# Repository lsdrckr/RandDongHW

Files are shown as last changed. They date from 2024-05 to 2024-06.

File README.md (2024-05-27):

# Stage chez Rang Dong

## Introduction

Dans le cadre de mon stage au Vietnam au Posts and Telecommunications Institute of Technologies, j'ai eu l'occasion de réaliser un projet avec une de leurs entreprise partenaire : Rand Dong. Cette entreprise est spécialisé dans la conception et la vente de matériel pour la domotique (smart home, smart cities...) tels que des lampes connectés, des hubs de capteurs (température, pression...) ou encore des caméras connectés. J'ai eu l'occasion de rejoindre 4 équipes :
- software : design d'application mobiles
- firmware : programmation de systèmes embarqués
- cloud : stockage dans des databases
- hardware : design de circuit imprimé
Mon choix s'est tourné vers le hardware, domaine dans lequel j'ai pu approfondir mes connaissances, et ce principalement d'un point de vue technique, grâce à l'équipe de Rang Dong qui m'a épaulé durant l'entièreté de mon stage.

## Projet

Le projet qui m'a été confié fût de réalisé un "Touch switch". Il s'agit d'interrupteurs tactiles permettant de contrôler, dans le cas de mon projet, 4 lampes. Voici ci-dessous une photo d'un produit commercialisé par Rand Dong sur lequel je vais me baser.

<center>
  <table>
    <tr>
      <td align="center">
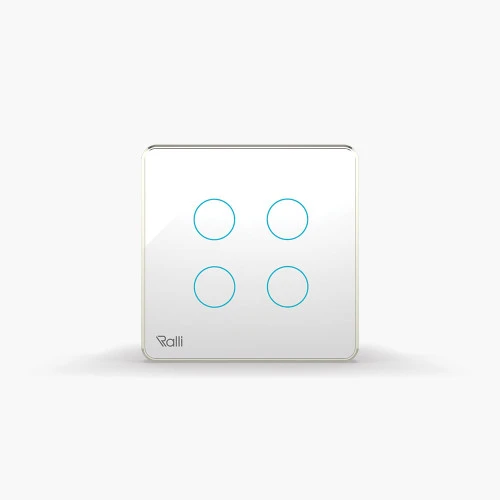
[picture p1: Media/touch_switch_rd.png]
touch_switch_rd
        
        <br>
        <em>Touch Switch de chez Rang Dong</em>
      </td>
    </tr>
  </table>
</center>

A l'aide d'un contact avec le doigt sur l'un des ronds bleus, on allume une lampe à proximité. Ce principe à l'air simple car il est couramment utilisé et il nous accompagne au quotidien. Cependant, nous allons voir comment un tel projet est réalisé du début à la fin. Chez Rang Dong, ce genre d'objets est réalisé en 3 parties :
- une carte servant à l'alimentation (conversion AC/DC, relais...)
- une carte destiné au contrôle (microprocesseur...)
- le design de l'objet en lui-même, dans lequel sont camouflés les précédentes cartes
Dans un premier temps, j'ai conçu la carte servant à l'alimentation.

## Alimentation

### Choix des technologies

Le choix de l'alimentation est très importante pour tout projet, mais il l'est d'autant plus pour un projet comme celui-ci. En effet, ce dernier est destiné à n'importe quel client et de plus, ce client devra être en contact direct avec l'objet s'il souhaite l'utiliser. C'est pourquoi la sécurité était l'argument numéro un lors de mon choix. 2 propositions se sont vite dégagés au sein de l'équipe :
- alimentation buck
- alimentation flyback
D'un côté, l'alimentation buck permet la conversion à l'aide d'une inductance tandis que le flyback utilise un transformateur. De plus, le flyback permet une isolation galvanique entre la partie AC et la partie DC de la carte. Cependant, l'implémentation du flyback est plus compliqué que celle de l'alimentation buck. Comme dit précédemment, la sécurité de notre système est primordiale. Nous avons donc choisi l'alimentation flyback.

Nous avions besoin de récupérer 2 valeurs de tensions différents :
- une de 5V pour alimenter les relais
- une de 3.3V pour alimenter la carte de contrôle
Deux propositions sont égalements possible, dont voici les schémas équivalents :

<center>
  <table>
    <tr>
      <td align="center">
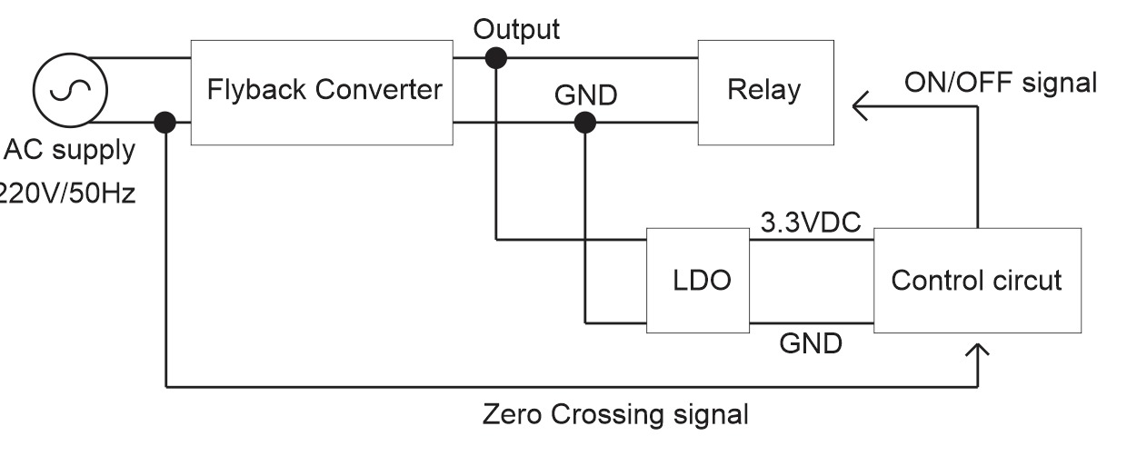
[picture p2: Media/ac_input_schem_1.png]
AC_input_schem1
        
        <br>
        <em>Proposition 1 pour l'alim AC</em>
      </td>
      <td align="center">
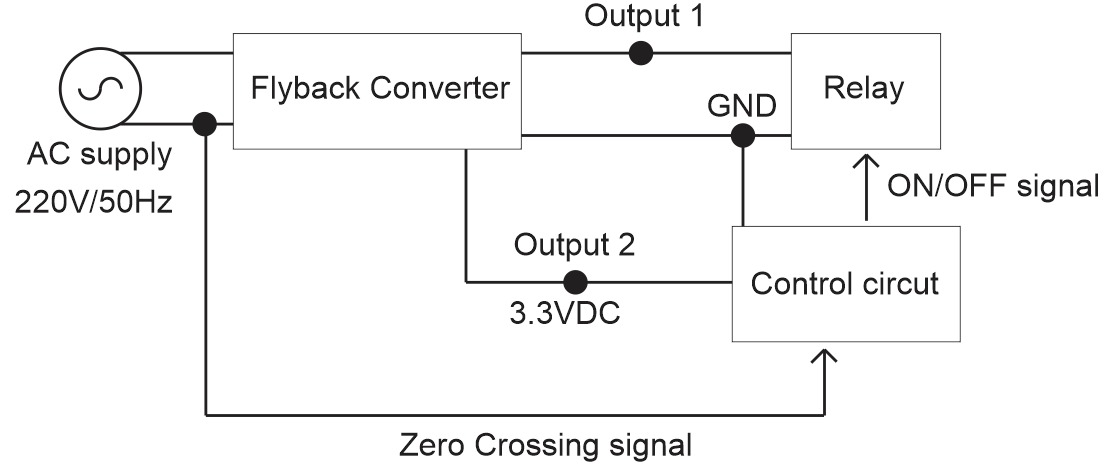
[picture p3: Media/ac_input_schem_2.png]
AC_input_schem2
        
        <br>
        <em>Proposition 2 pour l'alim AC</em>
      </td>
    </tr>
  </table>
</center>

Le premier choix consiste à utiliser 2 transformateurs ayant deux sorties et donc deux tensions de sortie différentes. Le deuxième, quant à lui, consiste à utiliser un régulateur de tension LDO pour récupérer 3.3V à partie des 5V de sortie du transformateur. Mon choix s’est naturellement posé sur le LDO, moins complexe à mettre en place et moins coûteux.
On mettra à l’entrée du transformateur un bloc snubber, permettant de limiter les pics de tension de l’alimentation AC et donc de protéger le transformateur.

### Choix des composants

Cette partie m’a énormément appris. Elle consiste non seulement à déterminer la valeurs des composants (résistances, capacités…) mais aussi à déterminer la taille des ses derniers en fonction de la puissance dissipée dans les résistances ou de la tension maximum des capacités. Pour les résistances, je me suis basé sur le tableau suivant venant de Fenghua.

<center>
  <table>
    <tr>
      <td align="center">
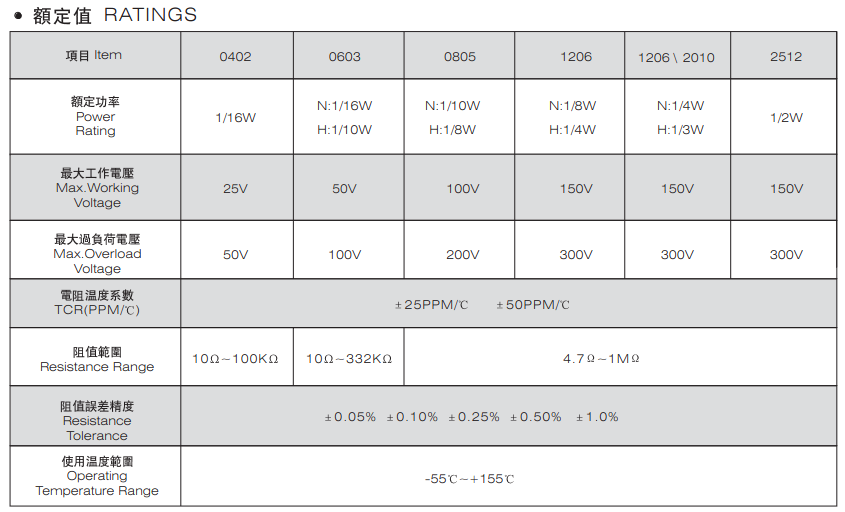
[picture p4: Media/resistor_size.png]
resistor_size
        
        <br>
        <em>Tableau de taille des résistances</em>
      </td>
    </tr>
  </table>
</center>

Pour les capacités, j’ai suivi le tableau de chez Kemet, qui donne la taille des composants en fonction de leurs valeurs et tension maximale.

<center>
  <table>
    <tr>
      <td align="center">
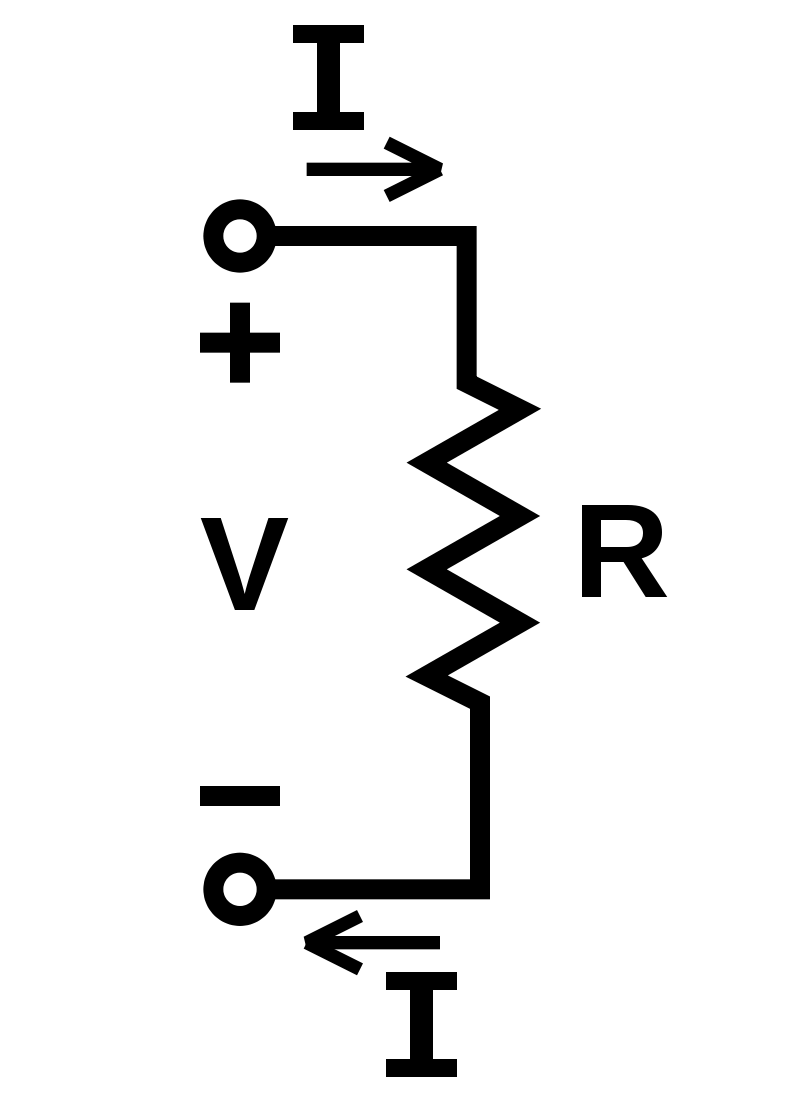
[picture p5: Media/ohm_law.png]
ohm_law
        
        <br>
        <em>Loi d'Ohm</em>
      </td>
    </tr>
  </table>
</center>

Pour mieux comprendre, voici un exemple rapide. Une résistance R est traversée par un courant I et a à ses bornes une tension V. La puissance qu’elle va dissiper est P = V\*I. En fonction de si l’on connaît seulement I ou V, on peut aussi déduire de la loi d'Ohm que P = V²/R ou P = I²\*R. Prenons dans notre exemple que nous avons déterminé R=1kΩ et Vmax=15V. On a alors P = 0,225W. En nous référant au tableau ci-dessus, on peut alors se permettre de choisir une résistance de taille 1206 ou plus, qui peut dissiper au maximum ¼W = 0,25W. Dans le cas où la puissance dépasse ½W, on peut mettre 2 résistances en parallèles, qui pourront dissiper 2 fois plus de puissance tout en gardant la même valeur. Prenons cette fois-ci Vmax=25V. On a alors P = 0,625W. En mettant deux résistances de 2kΩ en parallèle, on garde une résistance équivalente de 1kΩ et chacune d’entre elles doit seulement dissiper 0,3125W. Dans ce cas, on pourra choisir deux résistances de taille 2512.
Je n’ai pas détaillé le calcul pour chacun des composants, mais voici la méthode que j’ai suivie pour trouver leurs tailles.

### Implémentation sur Kicad

Maintenant que j’ai tous les éléments, je peux commencer à implémenter mon projet sur Kicad. J’ai séparé ce dernier en 4 grandes parties :

<center>
  <table>
    <tr>
      <td align="center">
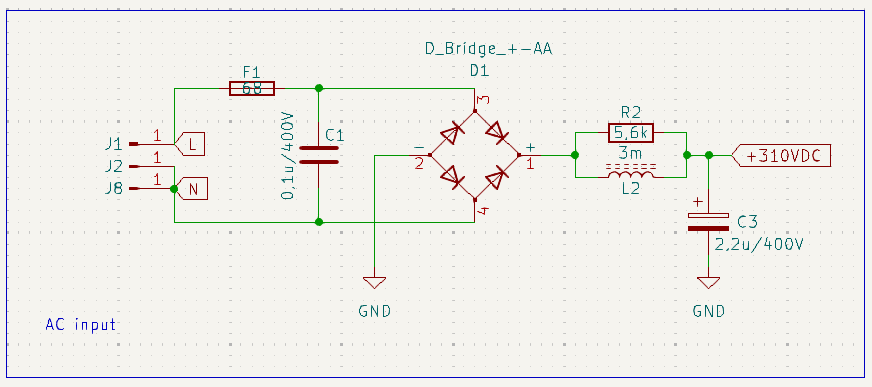
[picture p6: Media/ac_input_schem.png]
ac_input_schem
        
        <br>
        <em>Alimentation AC</em>
      </td>
      <td align="center">
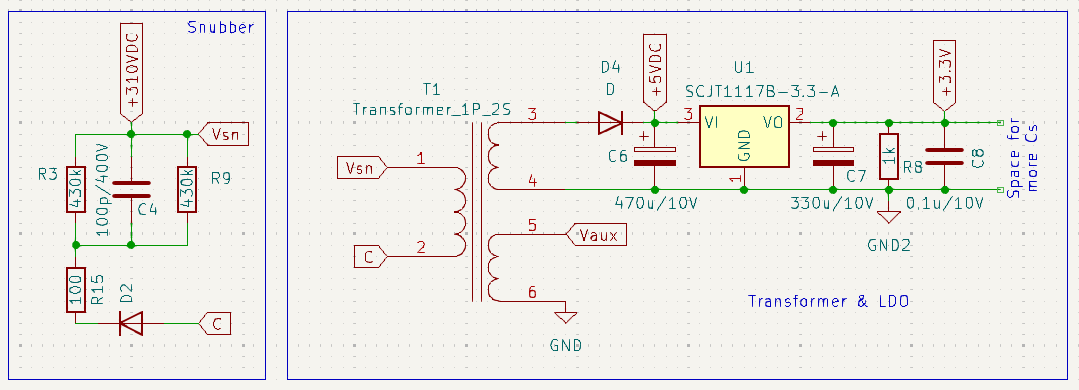
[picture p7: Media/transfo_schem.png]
transfo_schem
        
        <br>
        <em>Transformateur</em>
      </td>
    </tr>
    <tr>
      <td align="center">
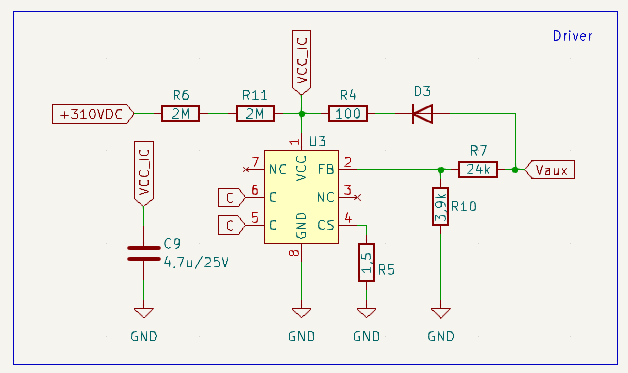
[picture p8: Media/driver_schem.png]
driver_schem
        
        <br>
        <em>Driver flyback</em>
      </td>
      <td align="center">
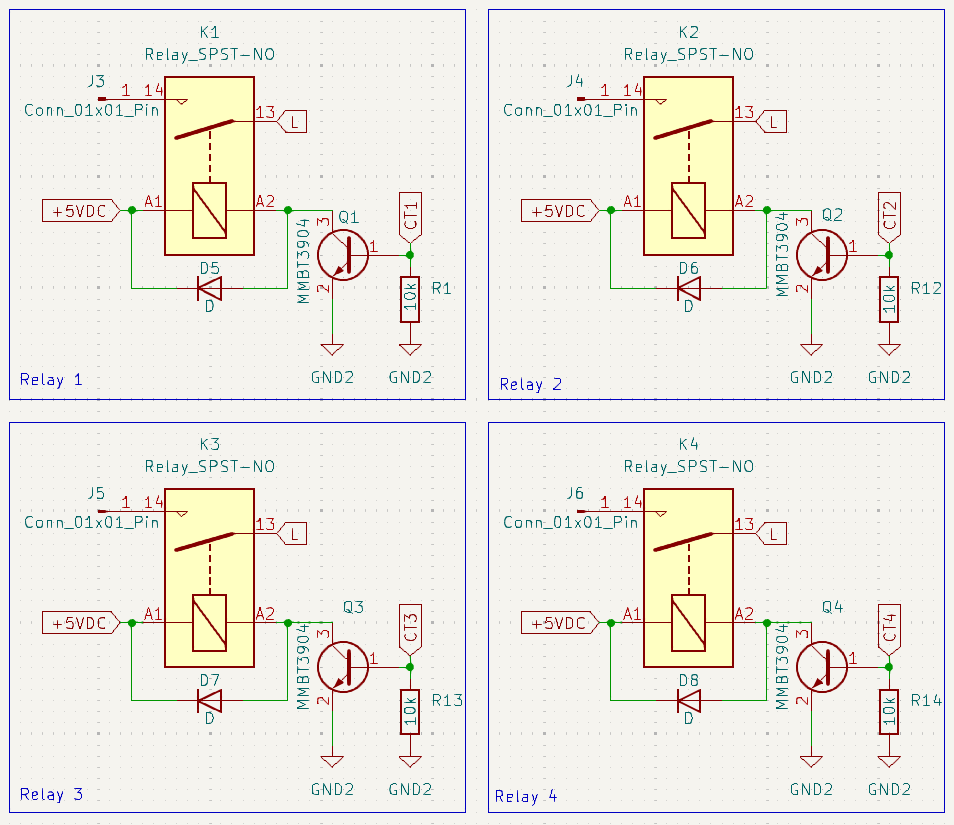
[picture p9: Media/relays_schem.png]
relays_schem
        
        <br>
        <em>Relais</em>
      </td>
    </tr>
  </table>
</center>

J’ai également ajouté un connecteur 8 pins pour relier cette carte à celle de contrôle auquel seront connectés les sorties des 4 relais, la sortie du régulateur en 3.3V et la masse lui étant associée.
J’ai ensuite assigné chacun des éléments avec leurs empreintes, soit en choisissant les tailles définies précédemment, soit en demandant à mon équipe les datasheets qu’ils ont l’habitude d’utiliser pour les composants “spéciaux” tels que le driver, le transformateur, les relais…

## Bibliographie

[Page git du projet](https://github.com/lsdrckr/RangDongHW.git)

[Taille des résistances](https://www.fenghua.com/pdf/thickfilmchipres/thin_film_chipres.pdf)

[Taille des condensateurs](https://www.mouser.com/datasheet/2/447/KEM_A4005_ESH-3315849.pdf)

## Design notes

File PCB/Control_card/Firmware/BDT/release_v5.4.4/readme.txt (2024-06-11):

Note:
   Error happens when BDT is opened, please fix it as the following step 
WIN 32:
   if your PC NOT have msvcr120.dll， Please move msvcr120.dll in the directory "./mevcr120" to "C:\Windows\System32" 

WIN 64:
   if your PC NOT have msvcr120.dll， Please move msvcr120.dll in the directory "./mevcr120" to "C:\Windows\SysWOW64"

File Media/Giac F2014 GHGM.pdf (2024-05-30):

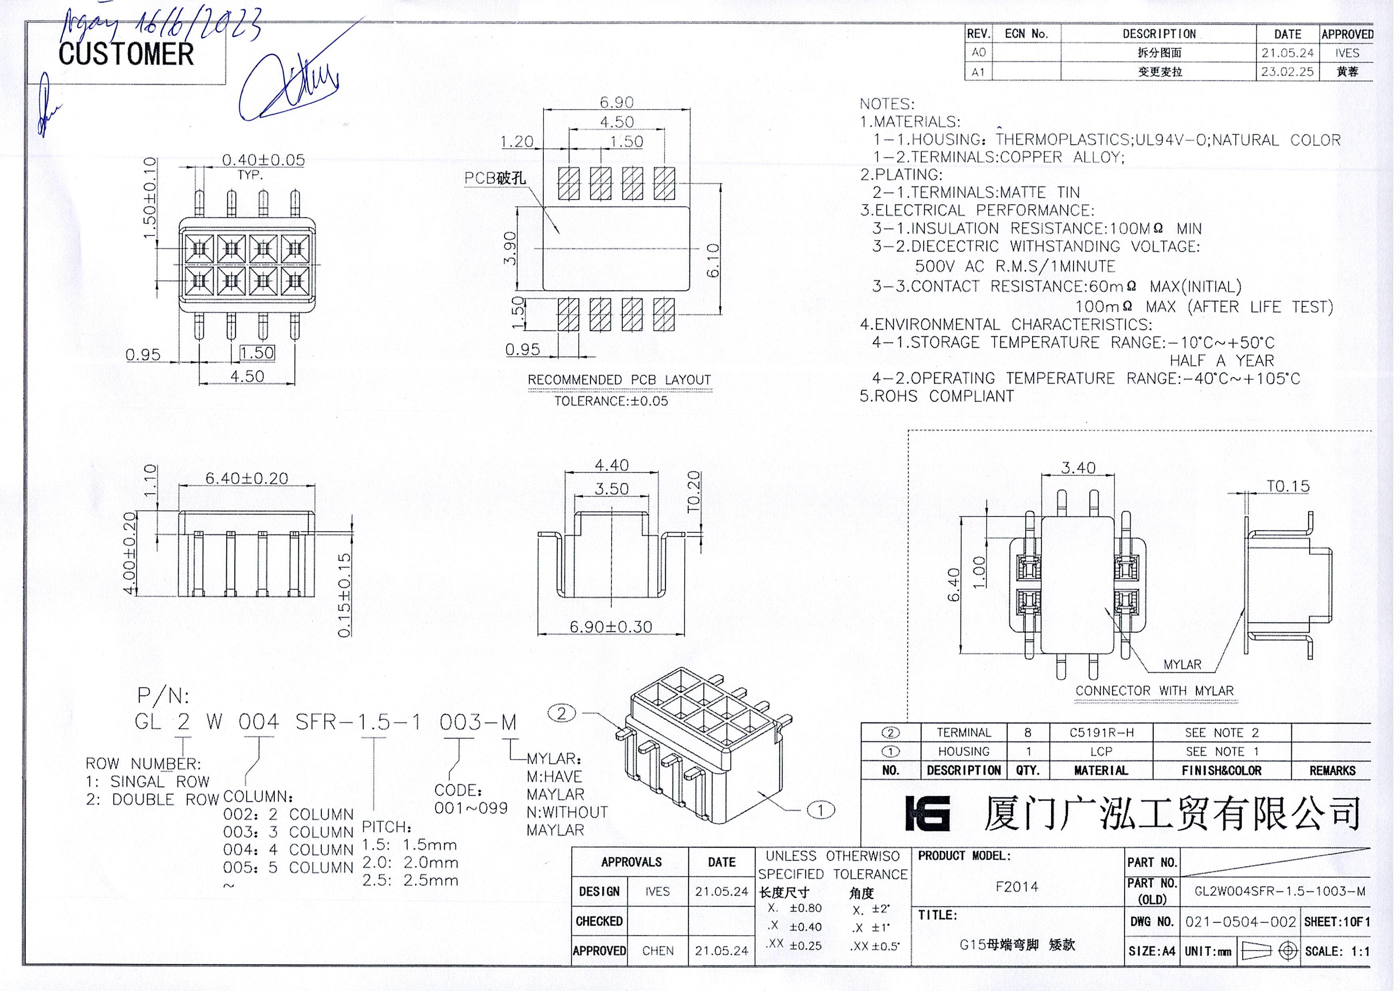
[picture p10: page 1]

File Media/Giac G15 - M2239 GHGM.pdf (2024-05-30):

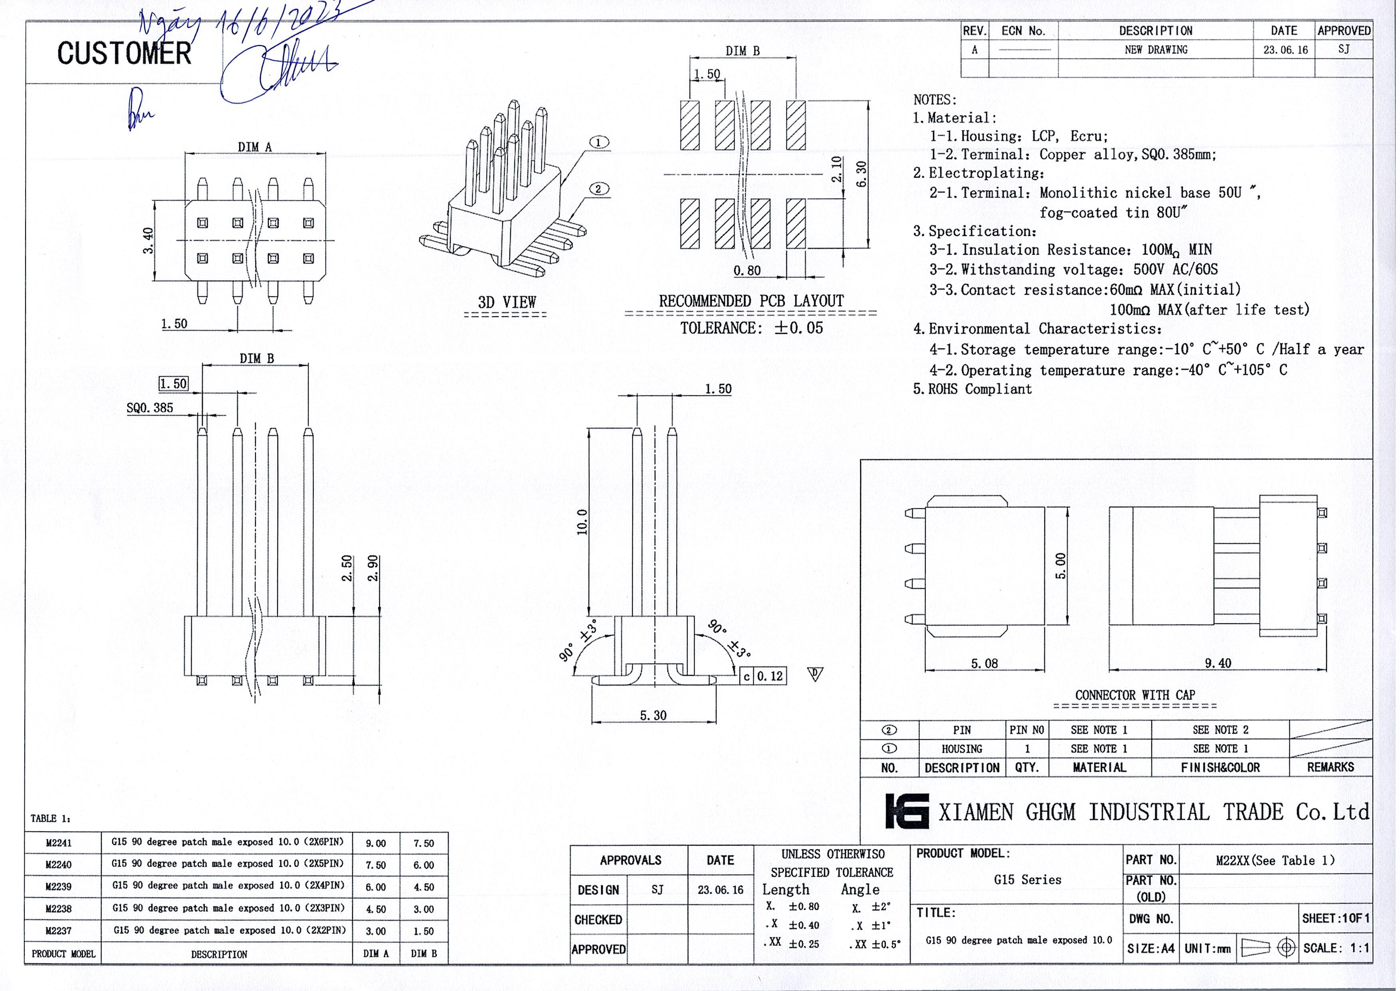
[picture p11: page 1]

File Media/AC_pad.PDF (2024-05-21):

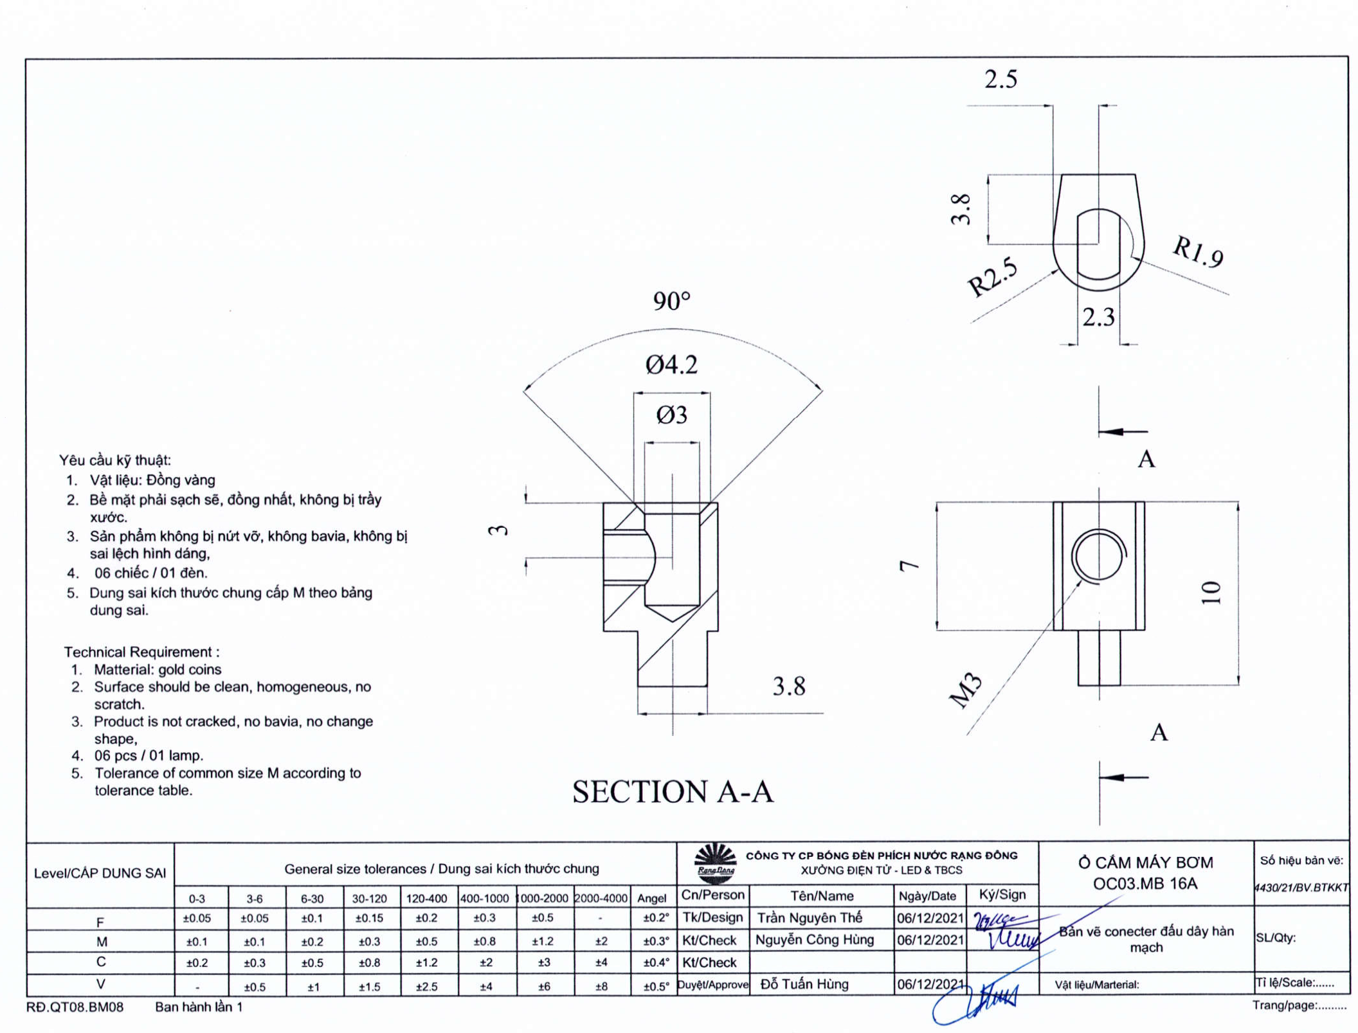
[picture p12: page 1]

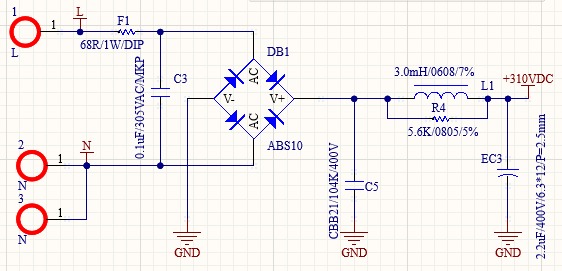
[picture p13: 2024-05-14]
Media/ac_input_bloc.png

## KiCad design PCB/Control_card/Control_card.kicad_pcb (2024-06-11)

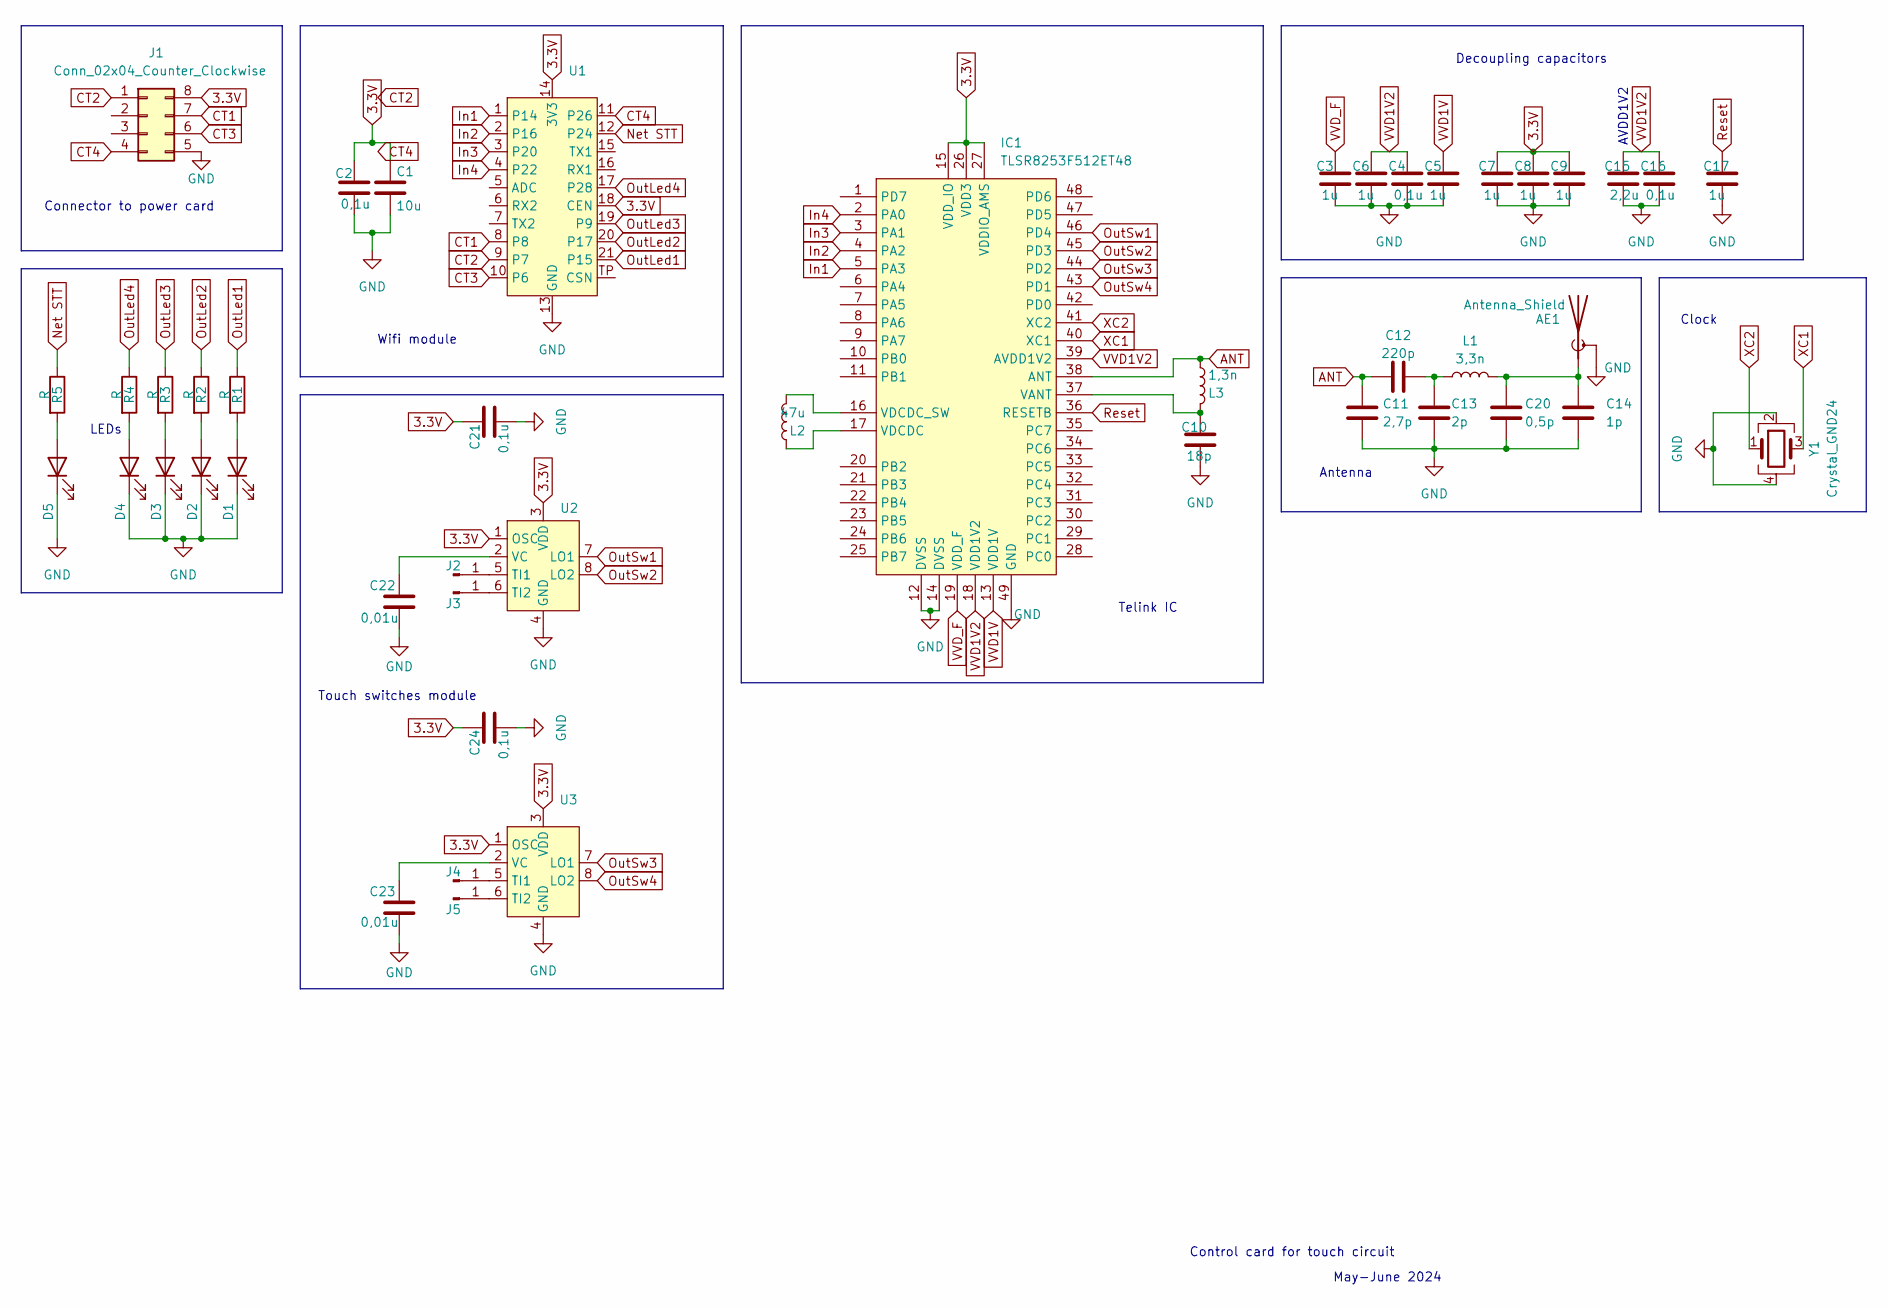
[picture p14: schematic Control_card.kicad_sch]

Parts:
AE1: Antenna_Shield; Antenna
C1: 10u; C_0603_1608Metric
C2, C4, C16, C21, C24: 0,1u; C_0603_1608Metric
C3, C5, C6, C7, C8, C9, C17: 1u; C_0603_1608Metric
C10: 18p; C_0603_1608Metric
C11: 2,7p; C_0603_1608Metric
C12: 220p; C_0603_1608Metric
C13: 2p; C_0603_1608Metric
C14: 1p; C_0603_1608Metric
C15: 2,2u; C_0603_1608Metric
C20: 0,5p; C_0603_1608Metric
C22, C23: 0,01u; C_0603_1608Metric
D1, D2, D3, D4, D5: LED; LED_0805_2012Metric
IC1: TLSR8253F512ET48; QFN-48-1EP_7x7mm_P0.5mm_EP5.6x5.6mm_ThermalVias; Mouser Part Number 141-TLSR8253F512ET32
J1: Conn_02x04_Counter_Clockwise; PinMale
J2, J3, J4, J5: Conn_01x01_Pin; TouchSwitch
L1: 3,3n; L_0603_1608Metric
L2: 47u; L_0805_2012Metric
L3: 1,3n; L_0603_1608Metric
R1, R2, R3, R4, R5: R; R_0603_1608Metric
U1: BK7231N
U2, U3: SOP-8_3.9x4.9mm_P1.27mm
Y1: Crystal_GND24; Crystal

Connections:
3.3V: C1.1, C2.1, C7.1, C8.1, C9.1, C21.1, C24.1, IC1.15 (VDD_IO), IC1.26 (VDD3), IC1.27 (VDDIO_AMS), J1.8, U1.14 (3V3), U1.18 (CEN), U2.1 (OSC), U2.3 (VDD), U3.1 (OSC), U3.3 (VDD)
ANT: C11.1, C12.1, IC1.38 (ANT), L3.2
CT1: J1.7, U1.8
CT2: J1.1, U1.9 (P7)
CT3: J1.6, U1.10 (P6)
CT4: J1.4, U1.11 (P26)
GND: AE1.2 (Shield), C1.2, C2.2, C3.2, C4.2, C5.2, C6.2, C7.2, C8.2, C9.2, C10.2, C11.2, C13.2, C14.2, C15.2, C16.2, C17.2, C20.2, C21.2, C22.2, C23.2, C24.2, D1.1 (K), D2.1 (K), D3.1 (K), D4.1 (K), D5.1 (K), IC1.12 (DVSS), IC1.14 (DVSS), IC1.49 (GND), J1.5, U1.13 (GND), U2.4 (GND), U3.4 (GND), Y1.2, Y1.4
In1: IC1.5 (PA3), U1.1 (P14)
In2: IC1.4 (PA2), U1.2 (P16)
In3: IC1.3 (PA1), U1.3 (P20)
In4: IC1.2 (PA0), U1.4 (P22)
Net STT: R5.1, U1.12 (P24)
unnamed: AE1.1 (A), C14.1, C20.1, L1.2
unnamed: C12.2, C13.1, L1.1
unnamed: D1.2 (A), R1.2
unnamed: D2.2 (A), R2.2
unnamed: D3.2 (A), R3.2
unnamed: D4.2 (A), R4.2
unnamed: D5.2 (A), R5.2
unnamed: C10.1, IC1.37 (VANT), L3.1
unnamed: IC1.17 (VDCDC), L2.1
unnamed: IC1.16 (VDCDC_SW), L2.2
unnamed: J2.1, U2.5 (TI1)
unnamed: J3.1, U2.6 (TI2)
unnamed: J4.1, U3.5 (TI1)
unnamed: J5.1, U3.6 (TI2)
unnamed: C22.1, U2.2 (VC)
unnamed: C23.1, U3.2 (VC)
OutLed1: R1.1, U1.21 (P15)
OutLed2: R2.1, U1.20 (P17)
OutLed3: R3.1, U1.19 (P9)
OutLed4: R4.1, U1.17 (P28)
OutSw1: IC1.46 (PD4), U2.7 (LO1)
OutSw2: IC1.45 (PD3), U2.8 (LO2)
OutSw3: IC1.44 (PD2), U3.7 (LO1)
OutSw4: IC1.43 (PD1), U3.8 (LO2)
Reset: C17.1, IC1.36 (RESETB)
VVD1V: C5.1, IC1.13 (VDD1V)
VVD1V2: C4.1, C6.1, C15.1, C16.1, IC1.18 (VDD1V2), IC1.39 (AVDD1V2)
VVD_F: C3.1, IC1.19 (VDD_F)
XC1: IC1.40 (XC1), Y1.3
XC2: IC1.41 (XC2), Y1.1

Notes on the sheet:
Connector to power card
Wifi module
LEDs
Decoupling capacitors
May-June 2024
Control card for touch circuit
Antenna
Telink IC
Touch switches module
Clock
AVDD1V2

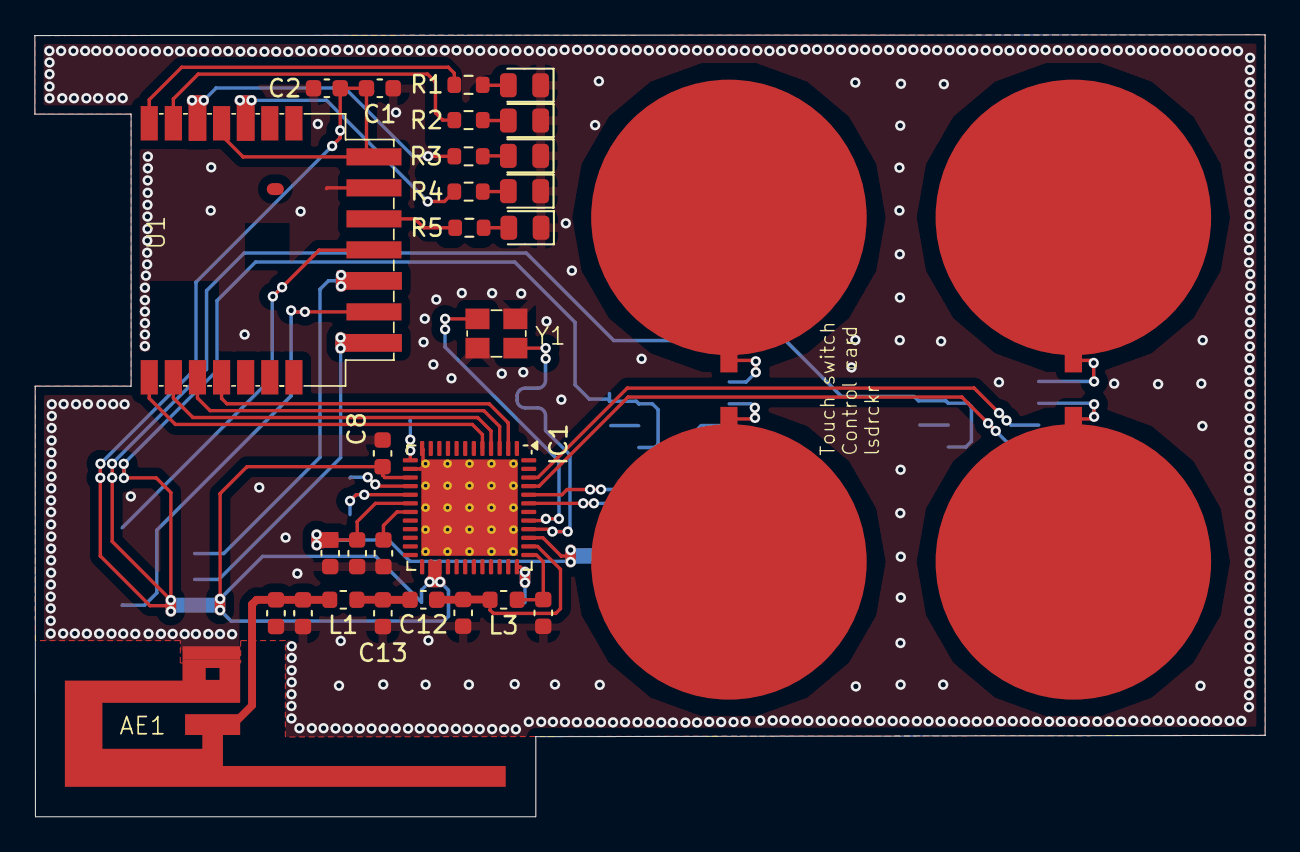
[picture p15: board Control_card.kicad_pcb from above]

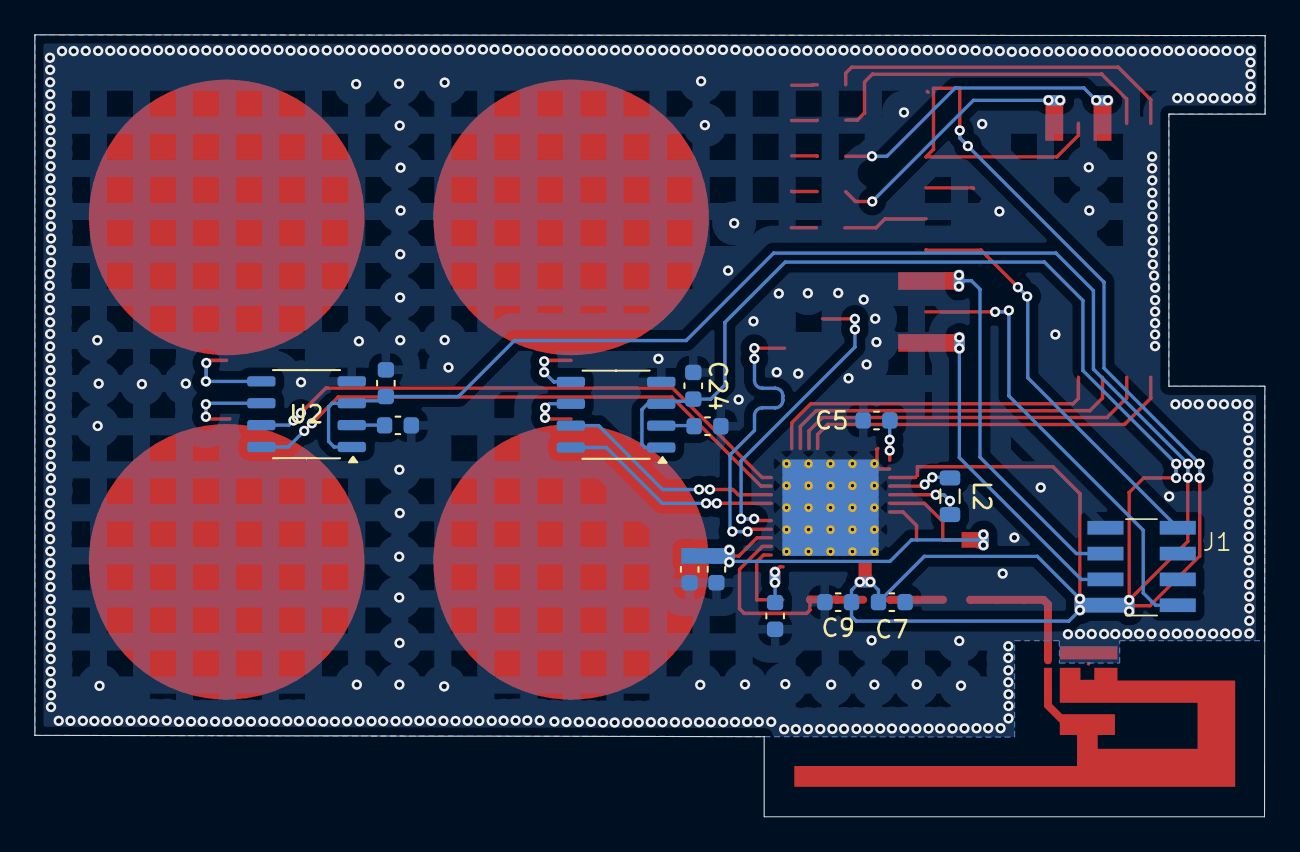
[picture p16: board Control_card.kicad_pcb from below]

Board: 2 copper layers, 71.4 x 45.4 mm, 46 parts (14 on the bottom side), 42 nets.

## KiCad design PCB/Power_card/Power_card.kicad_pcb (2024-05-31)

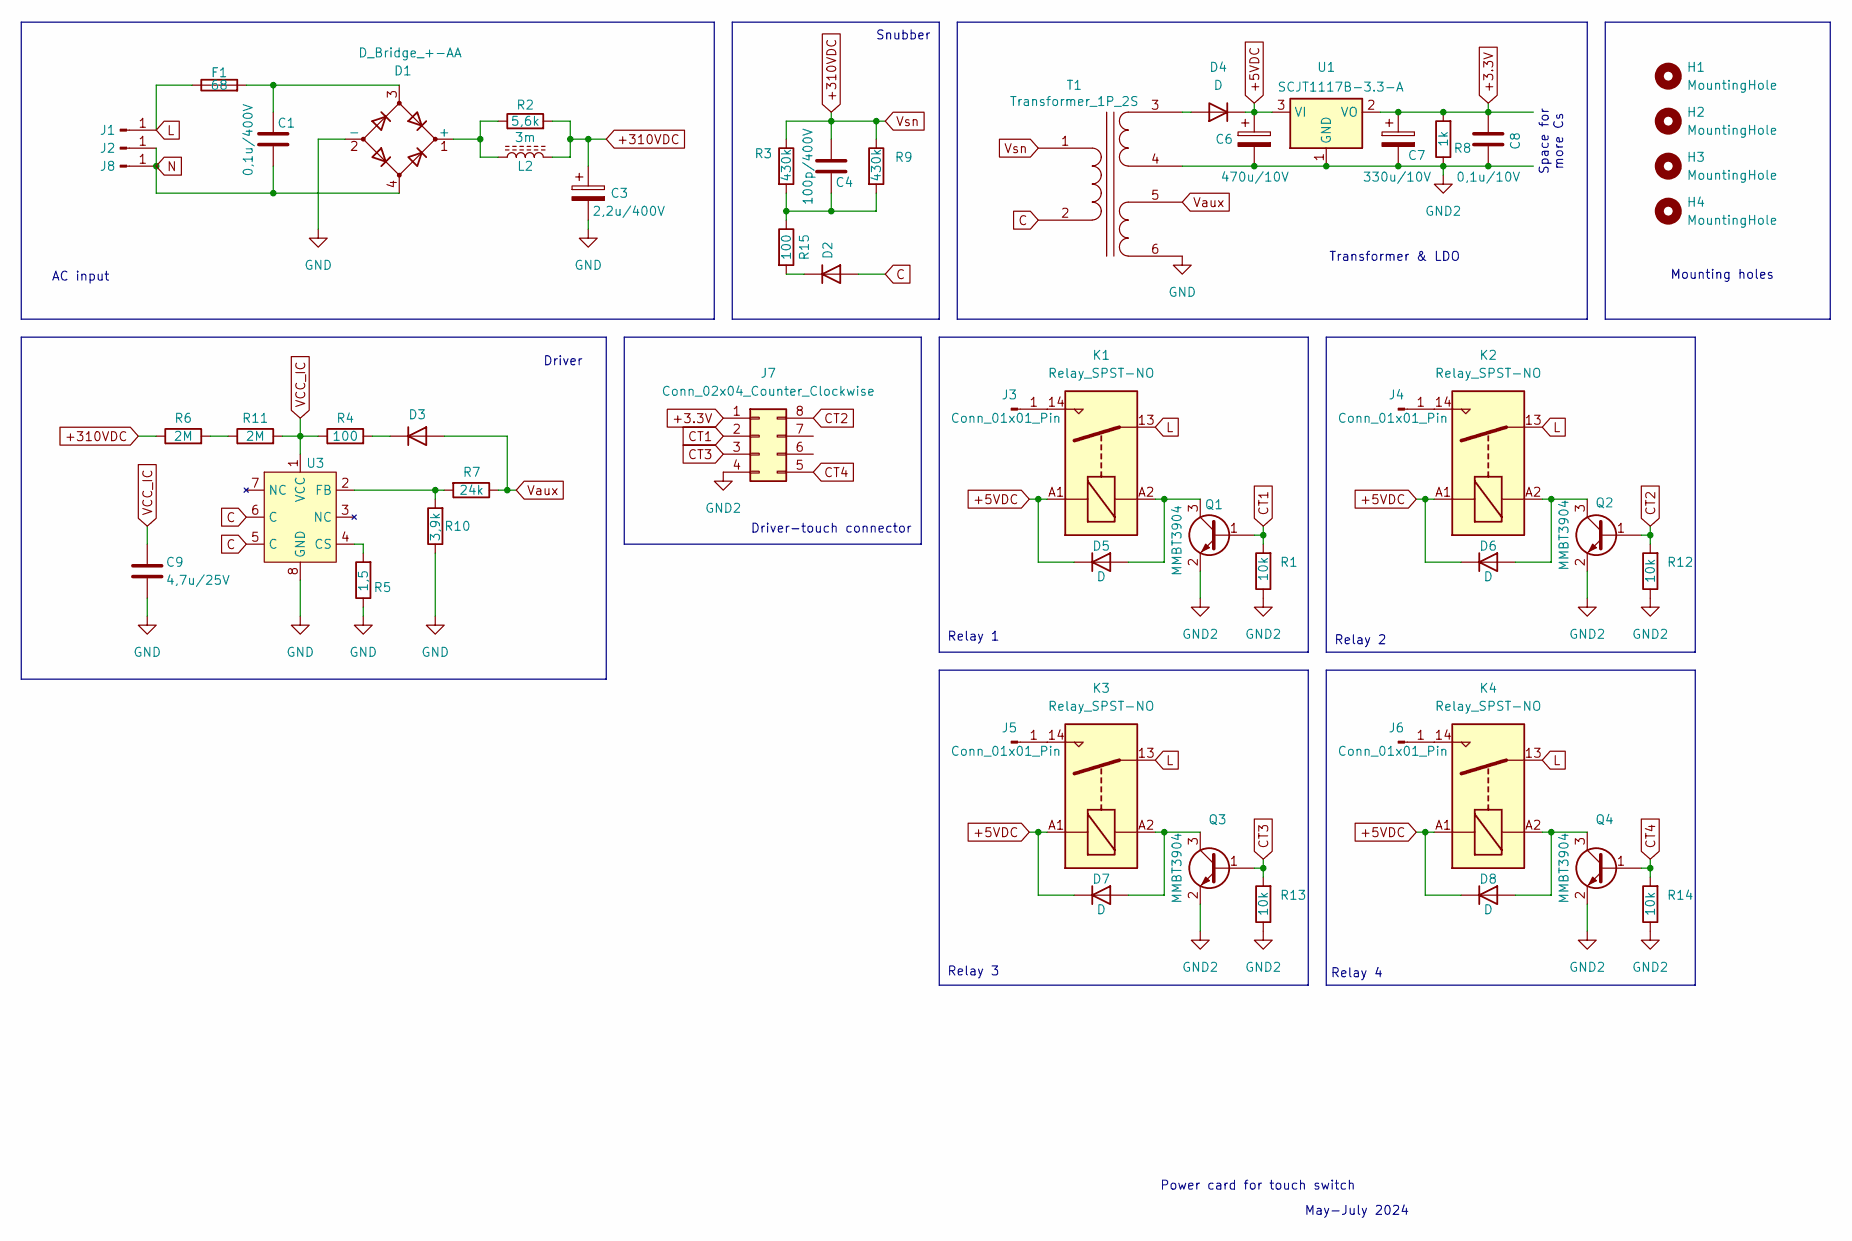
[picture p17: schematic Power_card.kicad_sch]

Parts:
C1: 0,1u/400V; MKP-X2-100NR10
C3: 2,2u/400V; CP_Radial_D8.0mm_P3.50mm
C4: 100p/400V; C_1206_3216Metric
C6: 470u/10V; CP_Radial_D8.0mm_P3.50mm
C7: 330u/10V; CP_Radial_D8.0mm_P3.50mm
C8: 0,1u/10V; C_0805_2012Metric
C9: 4,7u/25V; C_0805_2012Metric
D1: D_Bridge_+-AA; Diode_Bridge_Diotec_ABS
D2, D3, D4: D; D_SMA
D5, D6, D7, D8: D; D_SOD-123
F1: 68; Fuse
H1, H2, H3, H4: MountingHole; MountingHole_2.2mm_M2_Pad_Via
J1, J2, J3, J4, J5, J6, J8: Conn_01x01_Pin; AC_pad
J7: Conn_02x04_Counter_Clockwise; PinFemelle
K1, K2, K3, K4: Relay_SPST-NO; relay
L2: 3m; L_Radial_D7.5mm_P3.50mm_Fastron_07P
Q1, Q2, Q3, Q4: MMBT3904; SOT-23
R1, R12, R13, R14: 10k; R_0805_2012Metric
R2: 5,6k; R_1206_3216Metric
R3, R9: 430k; R_1206_3216Metric
R4: 100; R_0805_2012Metric
R5: 1,5; R_1206_3216Metric
R6, R11: 2M; R_1206_3216Metric
R7: 24k; R_1206_3216Metric
R8: 1k; R_0805_2012Metric
R10: 3,9k; R_1206_3216Metric
R15: 100; R_1206_3216Metric
T1: Transformer_1P_2S; Transformer_V2_1
U1: SCJT1117B-3.3-A; SOT-223-3_TabPin2
U3: SOP-8_3.9x4.9mm_P1.27mm

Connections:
+3.3V: C7.1, C8.2, J7.1, R8.2, U1.2 (VO)
+5VDC: C6.1, D4.1 (K), D5.1 (K), D6.1 (K), D7.1 (K), D8.1 (K), K1.A1, K2.A1, K3.A1, K4.A1, U1.3 (VI)
+310VDC: C3.1, C4.1, L2.2, R2.2, R3.1, R6.1, R9.1, T1.1 (AA)
C: D2.2 (A), T1.2 (AB), U3.5 (C), U3.6 (C)
CT1: J7.2, Q1.1 (B), R1.2
CT2: J7.8, Q2.1 (B), R12.2
CT3: J7.3, Q3.1 (B), R13.2
CT4: J7.5, Q4.1 (B), R14.2
GND: C3.2, C9.2, D1.2 (-), R5.1, R10.1, T1.6 (SD), U3.8 (GND)
GND2: C6.2, C7.2, C8.1, J7.4, Q1.2 (E), Q2.2 (E), Q3.2 (E), Q4.2 (E), R1.1, R8.1, R12.1, R13.1, R14.1, T1.4 (SB), U1.1 (GND)
L: F1.1, J1.1, K1.13, K2.13, K3.13, K4.13
N: C1.2, D1.4, J2.1, J8.1
unnamed: C1.1, D1.3, F1.2
unnamed: C4.2, R3.2, R9.2, R15.1
unnamed: D1.1 (+), L2.1, R2.1
unnamed: D2.1 (K), R15.2
unnamed: D3.1 (K), R4.2
unnamed: D4.2 (A), T1.3 (SA)
unnamed: D5.2 (A), K1.A2, Q1.3 (C)
unnamed: D6.2 (A), K2.A2, Q2.3 (C)
unnamed: D7.2 (A), K3.A2, Q3.3 (C)
unnamed: D8.2 (A), K4.A2, Q4.3 (C)
unnamed: J3.1, K1.14
unnamed: J4.1, K2.14
unnamed: J5.1, K3.14
unnamed: J6.1, K4.14
unnamed: R6.2, R11.1
unnamed: R5.2, U3.4 (CS)
unnamed: R7.2, R10.2, U3.2 (FB)
VCC_IC: C9.1, R4.1, R11.2, U3.1 (VCC)
Vaux: D3.2 (A), R7.1, T1.5 (SC)

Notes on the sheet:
Relay 2
Power card for touch switch
Relay 1
AC input
May-July 2024
Relay 4
Space for more Cs
Driver-touch connector
Snubber
Relay 3
Driver
Mounting holes
Transformer & LDO

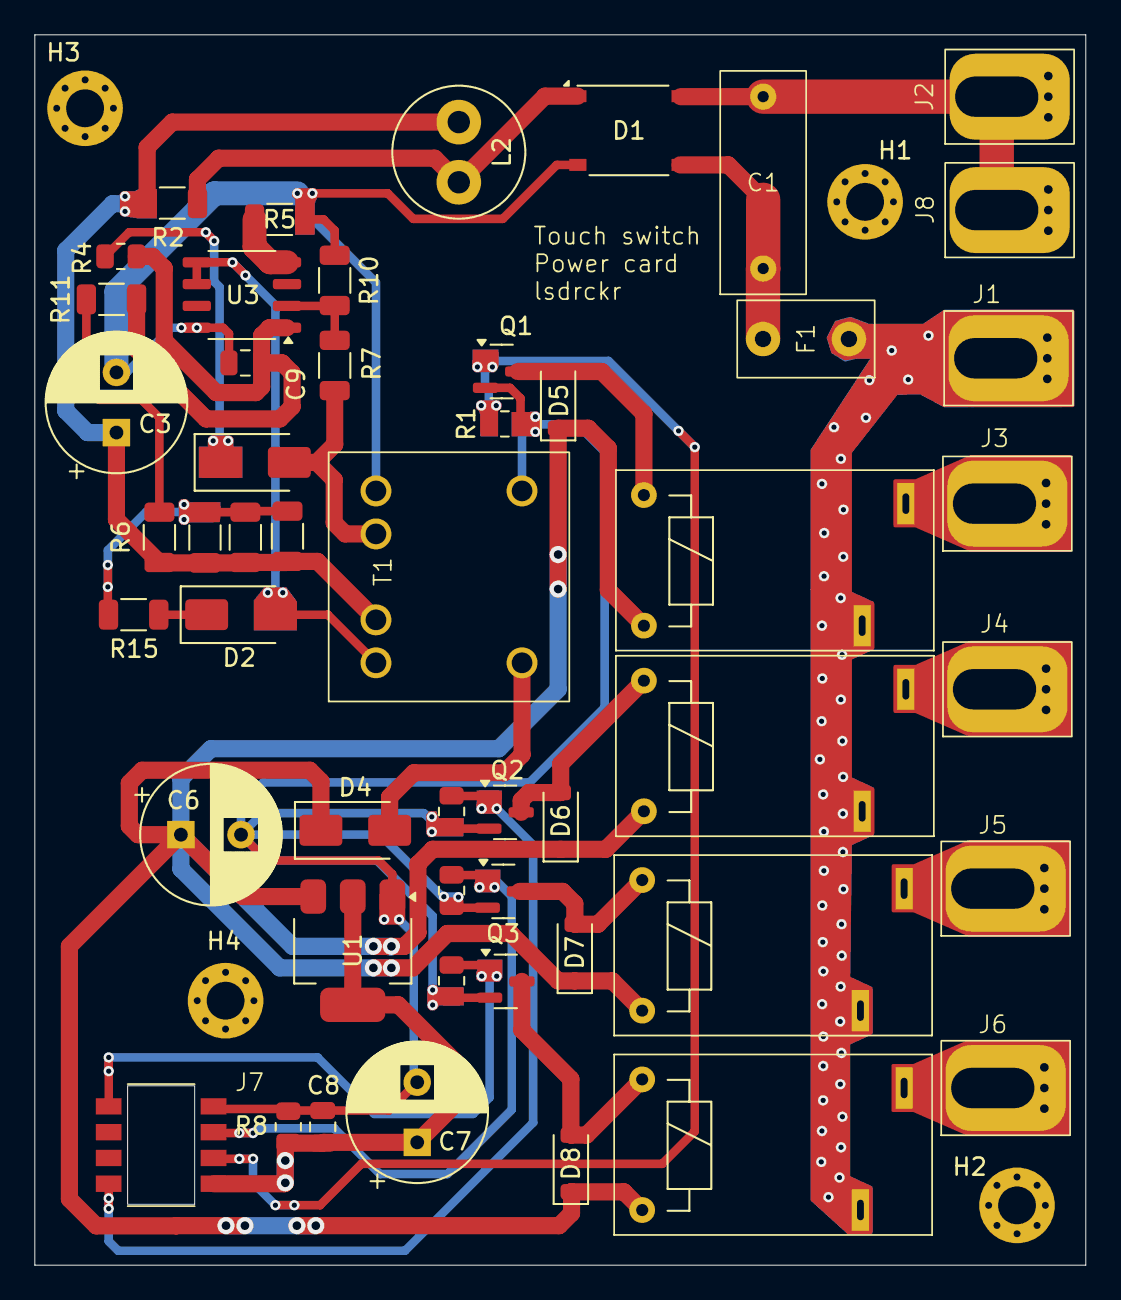
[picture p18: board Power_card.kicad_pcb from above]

Board: 2 copper layers, 61.2 x 71.6 mm, 55 parts (0 on the bottom side), 31 nets.

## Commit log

2024-05-13 Touch switch test
    [PCB_design.kicad_pcb, PCB_design.kicad_sch]
2024-05-14 Début bloc AC et Flyback/LDO
    [PCB_design.kicad_sch]
2024-05-16 Début schematic
    [PCB_design.kicad_sch, transfomer.xlsx]
2024-05-16 Assignation footprints
    [PCB_design.kicad_sch]
2024-05-17 Début routage
    [PCB_design.kicad_pcb, PCB_design.kicad_sch]
2024-05-17 Routage : regroupement des blocs
    [PCB_design.kicad_pcb, PCB_design.kicad_sch]
2024-05-20 Routage compact
    [PCB_design.kicad_pcb, PCB_design.kicad_sch]
2024-05-20 Routage compact & génération gerber
    [PCB_design-B_Cu.gbl, PCB_design-B_Mask.gbs, PCB_design-B_Paste.gbp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]
2024-05-20 Correction footprint relais
    [PCB_design-B_Cu.gbl, PCB_design-B_Mask.gbs, PCB_design-B_Paste.gbp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]
2024-05-20 Correction footprints relais et transfo
    [PCB_design-B_Cu.gbl, PCB_design-B_Mask.gbs, PCB_design-B_Paste.gbp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]
2024-05-20 Ajout mounting holes
    [PCB_design-B_Cu.gbl, PCB_design-B_Mask.gbs, PCB_design-B_Paste.gbp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]
2024-05-21 Ajout pads AC & modifs pistes
    [PCB_design.kicad_pcb, PCB_design.kicad_sch]
2024-05-21 Regroupement partie AC
    [PCB_design.kicad_pcb, taille_pistes.ods]
2024-05-21 J7 femelle
    [PCB_design.kicad_pcb, PCB_design.kicad_sch]
2024-05-21 Routage : séparation primaire/secondaire
    [PCB_design.kicad_pcb, PCB_design.kicad_sch]
2024-05-22 Rédaction README
    [PCB_design.kicad_pcb]
2024-05-22 Génération gerber
    [PCB_design-B_Cu.gbl, PCB_design-B_Mask.gbs, PCB_design-B_Paste.gbp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]
2024-05-23 Modif footprint relais & refaçonnage
    [PCB_design.kicad_pcb, PCB_design.kicad_sch]
2024-05-24 Modif vias
    [PCB_design.kicad_pcb]
2024-05-27 Projet renommé
    [PCB_design-B_Cu.gbl, PCB_design-B_Mask.gbs, PCB_design-B_Silkscreen.gbo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]
2024-05-27 Ajout carte de contrôle
    [Control_card.kicad_pcb, Control_card.kicad_sch]
2024-05-27 Début carte contrôle
    [Control_card.kicad_pcb, Control_card.kicad_sch, taille_pistes.ods]
2024-05-27 Ajout crystal
    [Control_card.kicad_pcb, Control_card.kicad_sch, Power_card.kicad_sch]
2024-05-28 Continuation routage & ajout antenne
    [Control_card.kicad_pcb, Control_card.kicad_sch]
2024-05-29 Finalisation carte contrôle
    [Control_card.kicad_pcb]
2024-05-29 Ajout des touch switch
    [Control_card.kicad_pcb, Control_card.kicad_sch, Power_card.kicad_pcb]
2024-05-30 Changement de connecteurs
    [Control_card.kicad_pcb, Control_card.kicad_sch, Power_card.kicad_pcb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]
2024-05-30 Ajout des footprints
    [Control_card.kicad_pcb, Control_card.kicad_sch, Power_card.kicad_pcb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]
2024-05-31 Rota IC contrôle
    [Control_card.kicad_pcb, Control_card.kicad_sch, Power_card.kicad_pcb]
2024-06-11 Ajout firmware
    [Control_card.kicad_pcb]
